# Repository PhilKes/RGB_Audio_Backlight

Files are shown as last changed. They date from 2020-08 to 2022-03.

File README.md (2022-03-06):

# RGB Audio Backlight
* WS2812B RGB LED Stripe + Arduino Nano
* Switching modes via Button
* Tweaking mode settings via Potentiometer

## See Instructables for details:  [Instructable](https://www.instructables.com/id/RGB-Backlight-MSGEQ7-Audio-Visualizer/)



## Audio Visualizer with MSGEQ7 Hardware
[RGBStripe_MSGEQ7](/RGBStripe_FFT)

* MSGEQ7 Circuit connected to Arduino
* Audio Spectrum Analyzer using MSGEQ7 Band outputs

## Audio Visualizer with Fast Fourier Transformation (FFT)

* Audio Spectrum Analyzer only using Software ([fix_fft](https://www.arduinolibraries.info/libraries/fix_fft))

### Schematic
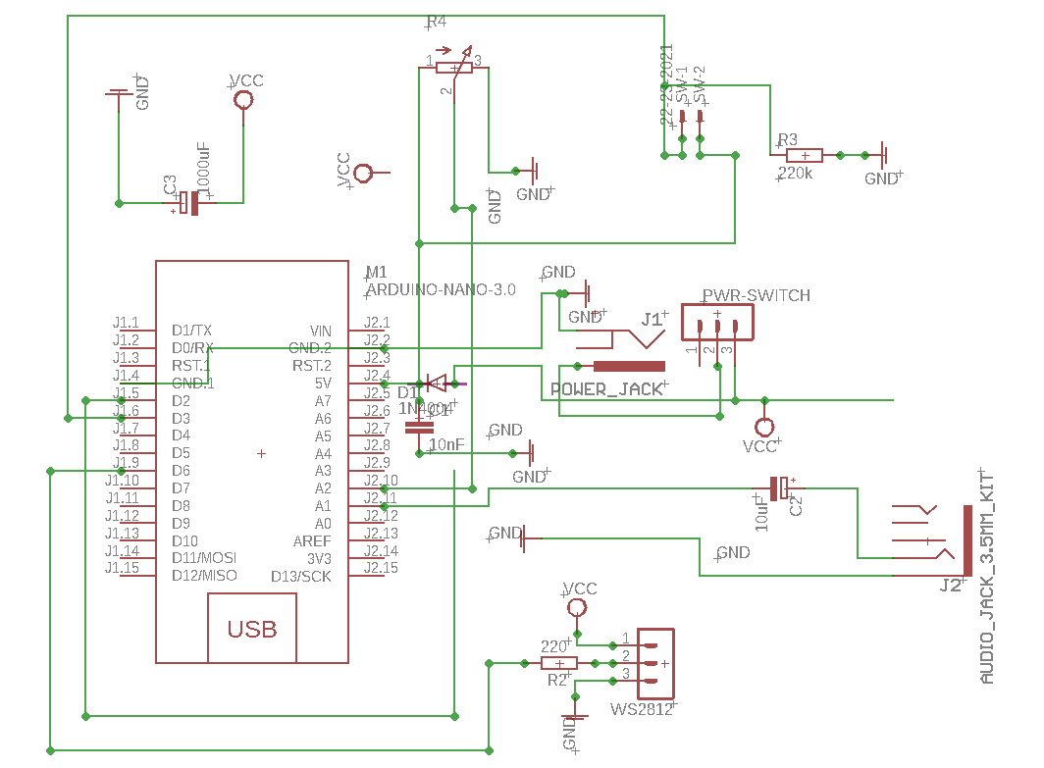
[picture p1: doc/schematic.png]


### 3D Printed Case
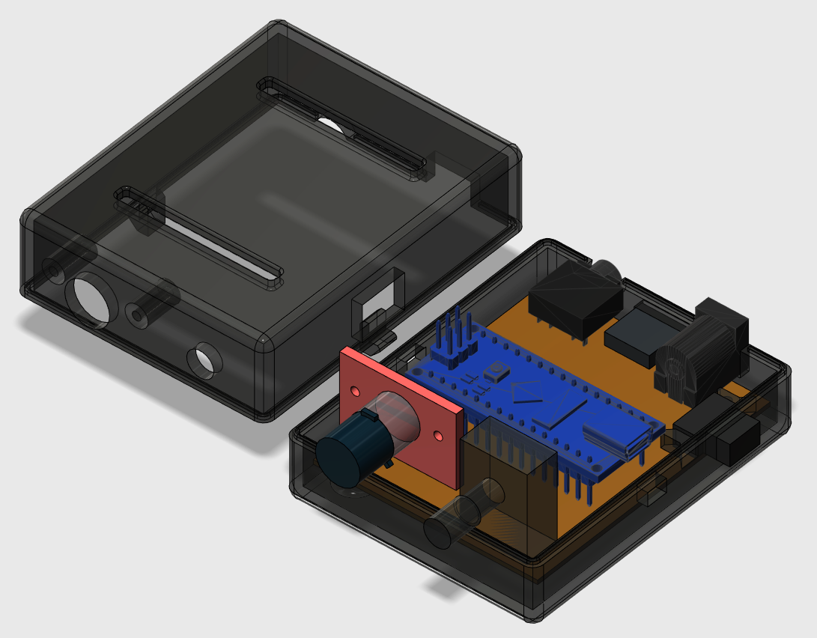
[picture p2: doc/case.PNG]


[RGBStripe_FFT](/RGBStripe_FFT)

* 3.5mm Aux connected to Analog Input of Arduino
* Audio Spectrum Analyzer using in Software FFT Algorithm to divide Signal in Audio Bands

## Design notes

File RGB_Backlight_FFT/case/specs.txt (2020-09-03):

Case:
Länge:69,90mm
Breite: 56.02mm
Wand Dicke: 2,4mm

button platine:
länge: 26mm
breite: 17mm

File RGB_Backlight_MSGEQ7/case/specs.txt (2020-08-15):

Touch Sensor:
länge 14mm
breite 11mm
dicke 1mm

Button Kappe
Höhe 9mm
durchmesser 10mm
ecken breit 1mm
ecken lang 3mm
pad höhe 7mm
pad durchmesser 10mm
pad -ecken übergang 1mm

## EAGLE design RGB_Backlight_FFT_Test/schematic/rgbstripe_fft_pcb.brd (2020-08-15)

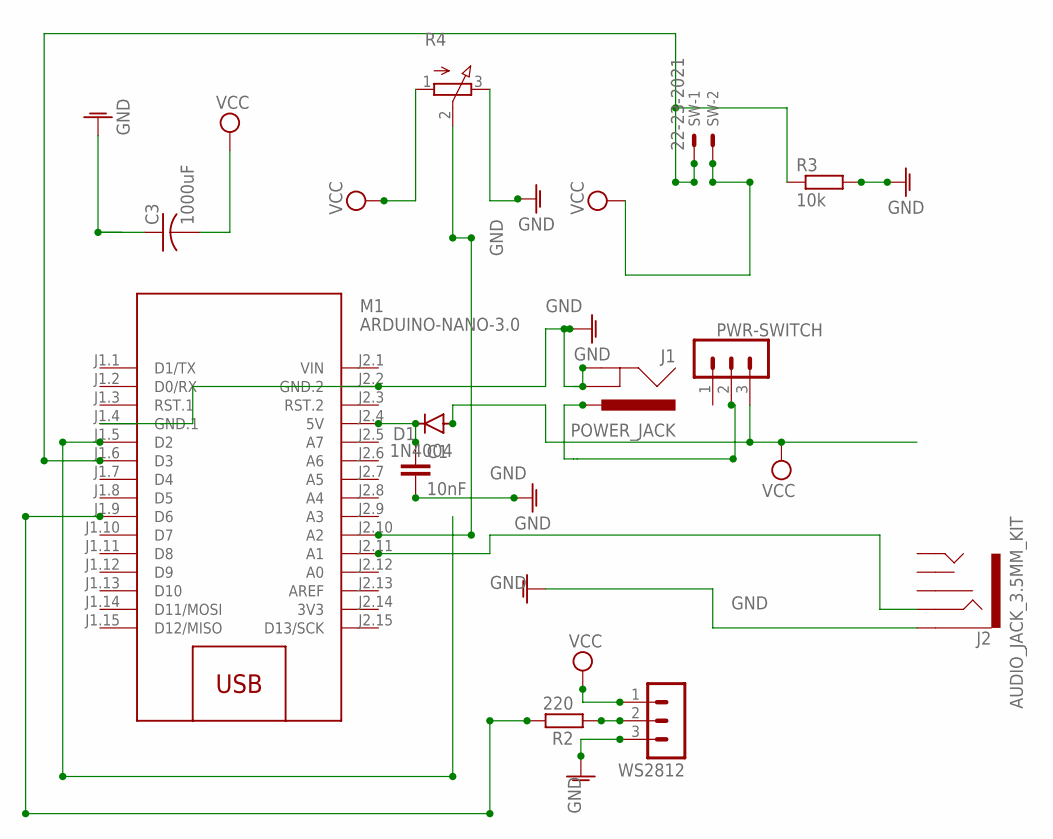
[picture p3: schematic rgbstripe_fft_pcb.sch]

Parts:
C1: 10nF; C025-025X050
C3: 1000uF; C050-024X044
D1: 1N4004; DO41-10
J1: POWER_JACK; POWER_JACK_PTH
J2: AUDIO_JACK_3.5MM_KIT; AUDIO-JACK-KIT
M1: ARDUINO-NANO-3.0
PWR-SWITCH: MA03-1
R2: 220; 0204/5
R3: 10k; 0204/5
R4: 3RP/1610N
SW: 22-23-2021
WS2812: MA03-1

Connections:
3V3: M1.J2.14 (3V3)
GND: C1.2, C3.1, J1.GND, J1.GNDBREAK, J2.SLEEVE, M1.J1.4 (GND.1), M1.J2.2 (GND.2), R3.2, R4.3 (E), WS2812.3
unnamed: C1.1, D1.C, M1.J2.4 (5V)
unnamed: J2.RING, M1.J2.11 (A1)
unnamed: M1.J1.9 (D6), R2.2
unnamed: M1.J2.10 (A2), R4.2 (S)
unnamed: R2.1, WS2812.2
unnamed: M1.J1.6 (D3), R3.1, SW.1
unnamed: J1.PWR, PWR-SWITCH.2
VCC: C3.2, D1.A, PWR-SWITCH.3, R4.1 (A), SW.2, WS2812.1
VIN: M1.J2.1 (VIN)

Board: 2 copper layers, 12 parts (0 on the bottom side), 9 nets, no tracks yet.

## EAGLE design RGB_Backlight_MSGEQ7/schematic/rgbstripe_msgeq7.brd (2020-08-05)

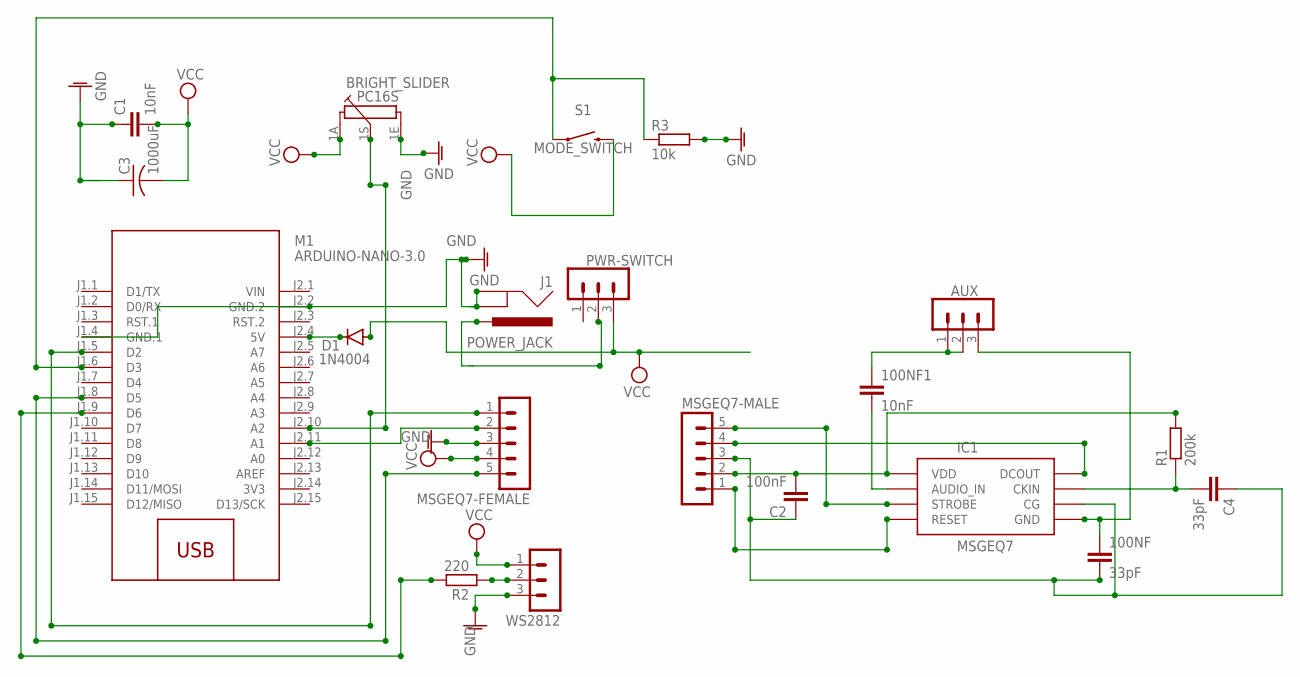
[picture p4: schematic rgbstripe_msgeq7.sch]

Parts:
100NF: 33pF; C025-025X050
100NF1: 10nF; C025-025X050
AUX: MA03-1
BRIGHT_SLIDER: PC16S
C1: 10nF; C025-025X050
C2: 100nF; C025-025X050
C3: 1000uF; C050-024X044
C4: 33pF; C025-025X050
D1: 1N4004; DO41-10
IC1: MSGEQ7P; DIP08
J1: POWER_JACK; POWER_JACK_PTH
M1: ARDUINO-NANO-3.0
MSGEQ7-FEMALE, MSGEQ7-MALE: MA05-1
PWR-SWITCH: MA03-1
R1: 200k; 0204/5
R2: 220; 0204/5
R3: 10k; 0204/5
S1: MODE_SWITCH; TACTILE_SWITCH_PTH_12MM
WS2812: MA03-1

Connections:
3V3: M1.J2.14 (3V3)
GND: BRIGHT_SLIDER.1E, C1.1, C3.1, J1.GND, J1.GNDBREAK, M1.J1.4 (GND.1), M1.J2.2 (GND.2), MSGEQ7-FEMALE.3, R3.2, WS2812.3
unnamed: D1.C, M1.J2.4 (5V)
unnamed: M1.J1.8 (D5), MSGEQ7-FEMALE.5
unnamed: M1.J2.11 (A1), MSGEQ7-FEMALE.2
unnamed: M1.J1.5 (D2), MSGEQ7-FEMALE.1
unnamed: C2.2, IC1.1 (VDD), MSGEQ7-MALE.2, R1.2
unnamed: 100NF.2, C2.1, C4.1, IC1.6 (CG), MSGEQ7-MALE.3
unnamed: IC1.3 (DCOUT), MSGEQ7-MALE.4
unnamed: IC1.4 (STROBE), MSGEQ7-MALE.5
unnamed: IC1.7 (RESET), MSGEQ7-MALE.1
unnamed: 100NF1.1, AUX.1, AUX.2
unnamed: C4.2, IC1.8 (CKIN), R1.1
unnamed: 100NF.1, AUX.3, IC1.2 (GND)
unnamed: 100NF1.2, IC1.5 (AUDIO_IN)
unnamed: M1.J1.9 (D6), R2.2
unnamed: BRIGHT_SLIDER.1S, M1.J2.10 (A2)
unnamed: R2.1, WS2812.2
unnamed: M1.J1.6 (D3), R3.1, S1.1
unnamed: J1.PWR, PWR-SWITCH.2
VCC: BRIGHT_SLIDER.1A, C1.2, C3.2, D1.A, MSGEQ7-FEMALE.4, PWR-SWITCH.3, S1.3 (2), WS2812.1
VIN: M1.J2.1 (VIN)

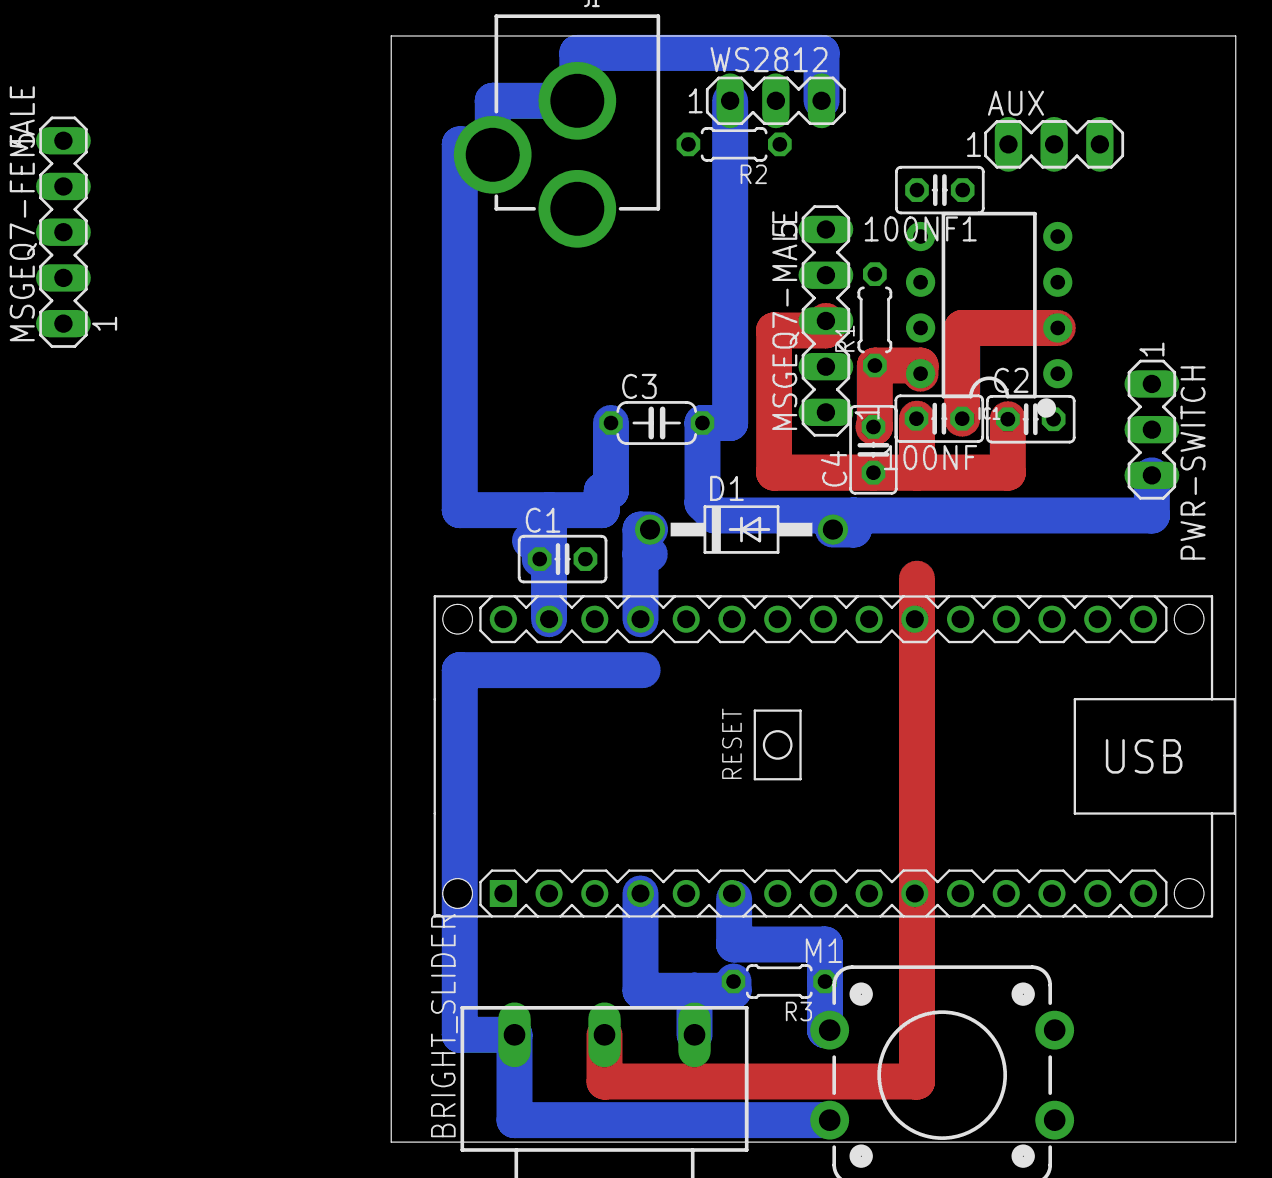
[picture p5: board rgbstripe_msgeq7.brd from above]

Board: 2 copper layers, 46.9 x 61.5 mm, 20 parts (0 on the bottom side), 20 nets.

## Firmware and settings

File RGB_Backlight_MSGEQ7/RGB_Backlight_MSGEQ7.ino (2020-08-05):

#include <Adafruit_NeoPixel.h>
#ifdef __AVR__
#include <avr/power.h>
#endif

#define LED_DATA 6
#define POT_BRIGHTNESS A2

#define NUM_LEDS 45         // <-- CHANGE TO NUMBER OF LEDS ON YOUR STRIP
#define BTN_PIN 3           // Button on Interrupt Pin 3         
#define BRIGHTNESS 255
#define MAX_MODE 7          // Amount of modes (used in Switch-Case)
#define DELAY 13

//  MSGEQ7 Pin Connections
#define MSGEQ_OUT A1
#define STROBE 2
#define RESET 5

//MINIMUM DELAY FOR BUTTON TO TRIGGER NEXT ISR
#define ISR_DELAY 400
Adafruit_NeoPixel strip = Adafruit_NeoPixel(NUM_LEDS, LED_DATA, NEO_GRB + NEO_KHZ800);

byte neopix_gamma[] = {
  0,  0,  0,  0,  0,  0,  0,  0,  0,  0,  0,  0,  0,  0,  0,  0,
  0,  0,  0,  0,  0,  0,  0,  0,  0,  0,  0,  0,  1,  1,  1,  1,
  1,  1,  1,  1,  1,  1,  1,  1,  1,  2,  2,  2,  2,  2,  2,  2,
  2,  3,  3,  3,  3,  3,  3,  3,  4,  4,  4,  4,  4,  5,  5,  5,
  5,  6,  6,  6,  6,  7,  7,  7,  7,  8,  8,  8,  9,  9,  9, 10,
  10, 10, 11, 11, 11, 12, 12, 13, 13, 13, 14, 14, 15, 15, 16, 16,
  17, 17, 18, 18, 19, 19, 20, 20, 21, 21, 22, 22, 23, 24, 24, 25,
  25, 26, 27, 27, 28, 29, 29, 30, 31, 32, 32, 33, 34, 35, 35, 36,
  37, 38, 39, 39, 40, 41, 42, 43, 44, 45, 46, 47, 48, 49, 50, 50,
  51, 52, 54, 55, 56, 57, 58, 59, 60, 61, 62, 63, 64, 66, 67, 68,
  69, 70, 72, 73, 74, 75, 77, 78, 79, 81, 82, 83, 85, 86, 87, 89,
  90, 92, 93, 95, 96, 98, 99, 101, 102, 104, 105, 107, 109, 110, 112, 114,
  115, 117, 119, 120, 122, 124, 126, 127, 129, 131, 133, 135, 137, 138, 140, 142,
  144, 146, 148, 150, 152, 154, 156, 158, 160, 162, 164, 167, 169, 171, 173, 175,
  177, 180, 182, 184, 186, 189, 191, 193, 196, 198, 200, 203, 205, 208, 210, 213,
  215, 218, 220, 223, 225, 228, 231, 233, 236, 239, 241, 244, 247, 249, 252, 255
};

uint16_t time_since_isr=0;
boolean breakMode=false;
uint8_t mode=0;
//  Buffer arrays for Audio Analyzer Mode
int spectrumValue[8];
uint8_t mapValue[8];
uint32_t audioBuffer[NUM_LEDS];
int filter = 0;

uint16_t brightness;

bool countUp=true;
uint32_t lastColor=0;

void setup() {
  // This is for Trinket 5V 16MHz, you can remove these three lines if you are not using a Trinket
#if defined (__AVR_ATtiny85__)
  if (F_CPU == 16000000) clock_prescale_set(clock_div_1);
#endif
  // Init Strip with max. Brightness
  brightness = BRIGHTNESS;
  strip.setBrightness(BRIGHTNESS);
  strip.begin();
  strip.show();

  //Serial connection for debug info
  Serial.begin(9600);
  Serial.println("START");
  pinMode(MSGEQ_OUT, INPUT);
  pinMode(STROBE, OUTPUT);
  pinMode(RESET, OUTPUT);
  pinMode(BTN_PIN, INPUT);
  
  digitalWrite(RESET, LOW);
  digitalWrite(STROBE, HIGH);

  pinMode(POT_BRIGHTNESS, INPUT);
  // Attach interrupt to Pin 3 for Push Button to switch modes
  attachInterrupt(1, changeMode, RISING);
}

void loop() {
  breakMode=false;
  switch(mode){
    case 0:
      Serial.println("White");
      plainColorNoBright(255,255,255);
      break;
   case 1:                        // CHANGE IF NOT USING MSGEQ7
      Serial.println("Music");
      musicAnalyzer();
      break;
   case 2:
      Serial.println("Red");
      plainColor(255,0,0);
      break;
    case 3:
      Serial.println("Green");
      plainColor(0,255,0);
      break;
    case 4:
      Serial.println("Blue");
      plainColor(0,0,255);
      break;
   case 5:
      Serial.println("Raindow");
      rainbowFade2White(400,255,10);
      break;
   case 6:
      Serial.println("ColorRoom");
      colorRoom();
      break;
   default:
      Serial.println("DEFAULT");
      pulseWhite(300);
      break;
  }
}

/* ISR for Button to switch modes */
void changeMode() {
  if(millis()-time_since_isr>ISR_DELAY){
    Serial.println("PRESSED");
    time_since_isr=millis();
    mode=(mode+1)%MAX_MODE;
    breakMode=true;
  }
}
/* Checks if Potentiometer value has changed, sets new Brightness and return true */
boolean checkBrightness(){
  //WS2812 takes value between 0-255
  uint16_t bright = map(constrain(analogRead(POT_BRIGHTNESS),0,1024), 0, 1024, 10, 255);
  if (abs(bright-brightness)>10){
    brightness = bright;
    strip.setBrightness(brightness);
    return true;
  }
  return false;
}

//Animation showing fading rainBow color along the strip
void rainbowFade2White(uint8_t wait, int rainbowLoops, int whiteLoops) {
  float fadeMax = 100.0;
  int fadeVal = fadeMax;
  uint32_t wheelVal;
  int redVal, greenVal, blueVal;

  for (int k = 0 ; k < rainbowLoops ; k ++) {
    for (int j = 0; j < 256; j++) { 
      for (int i = 0; i < strip.numPixels(); i++) {
        wheelVal = Wheel(((i * 256 / strip.numPixels()) + j) & 255);
        redVal = red(wheelVal) * float(fadeVal / fadeMax);
        greenVal = green(wheelVal) * float(fadeVal / fadeMax);
        blueVal = blue(wheelVal) * float(fadeVal / fadeMax);
        strip.setPixelColor( i, strip.Color( redVal, greenVal, blueVal ) );
      }
      if(breakMode)
        return;
        checkBrightness();
        strip.show();
        delay(wait);
    }
  }
  delay(500);
}

// Use Brightness Potentiometer to change Color
void colorRoom(){
    strip.setBrightness(255);
    uint32_t colorNew = map(constrain(analogRead(POT_BRIGHTNESS),0,1024), 0, 1024, 0, 255);
    if (abs(colorNew-lastColor)>10){
      lastColor=colorNew;
      for (int i = 0; i < strip.numPixels(); i++)
             strip.setPixelColor(i, Wheel((colorNew) & 255)); 
      strip.show();
    }
    delay(10);
}

void plainWhite(){
  for (int i = 0; i < strip.numPixels(); i++) {
        strip.setPixelColor( i, strip.Color( 255, 255, 255 ) );
   }
  strip.show();
  while(!breakMode){
    if(checkBrightness())
      strip.show();
  }
}

//Shows plain color along the strip
void plainColor(uint8_t red,uint8_t green,uint8_t blue){
  for (int i = 0; i < strip.numPixels(); i++)
        strip.setPixelColor( i, strip.Color( red, green, blue ) );
  strip.show();
  while(!breakMode){
    if(checkBrightness())
      strip.show();
  }
}

//Shows plain color along the strip
void plainColorNoBright(uint8_t red,uint8_t green,uint8_t blue){
  for (int i = 0; i < strip.numPixels(); i++)
        strip.setPixelColor( i, strip.Color( red, green, blue ) );
  strip.show();
  while(!breakMode){
    delay(100);
  }
}
void musicAnalyzer(){
  while(true){
    checkBrightness();
    if(breakMode)
      return;
    //Reset MSGEQ
    digitalWrite(RESET, HIGH);
    digitalWrite(RESET, LOW);
    //Read all 8 Audio Bands
    for (int i = 0; i < 8; i++){
      digitalWrite(STROBE, LOW);
      delayMicroseconds(30);
      spectrumValue[i] = analogRead(MSGEQ_OUT);
      spectrumValue[i] = constrain(spectrumValue[i], filter, 1023);
      digitalWrite(STROBE, HIGH);
      //Skip band 3 (seems to be random for my MSGEQ7, but feel free to check yours
      if (i == 3)
        continue;
      mapValue[i] = map(spectrumValue[i], filter, 1023, 0, 255);
      if (mapValue[i] < 50)
        mapValue[i] = 0;
    }
    //Shift LED values forward
    for (int k = NUM_LEDS - 1; k > 0; k--) {
      audioBuffer[k] = audioBuffer[k - 1];
    }
    //Uncomment / Comment above to Shift LED values backwards
    //for (int k = 0; k < NUM_LEDS-1; k++) {
    //  audioBuffer[k] = audioBuffer[k + 1];
    //}
    
    //Load new Audio value to first LED
    //Uses band 0,2,4 (Bass(red), Middle(green), High(blue) Frequency Band)
    //Lowest 8Bit: Blue , Middle Green , Highest Red
    //Use audioBuffer[NUM_LEDS-1] when using LED shift backwards!
    audioBuffer[0] = mapValue[5]; //RED
    audioBuffer[0] = audioBuffer[0] << 16;
    audioBuffer[0] |= ((mapValue[2] /2) << 8);  //GREEN
    audioBuffer[0] |= (mapValue[4]/4);         //BLUE
    
    //Send new LED values to WS2812
    for ( int i = 0; i < NUM_LEDS; i++)
      strip.setPixelColor(i, strip.Color(audioBuffer[i] >> 16, (audioBuffer[i] >> 8)&B11111111, audioBuffer[i]&B11111111));
    strip.show();
    delay(DELAY);
  }
}

//  FROM EXAMPLES
// Fill the dots one after the other with a color
void colorWipe(uint32_t c, uint8_t wait) {
  for (uint16_t i = 0; i < strip.numPixels(); i++) {
    strip.setPixelColor(i, c);
    strip.show();
    delay(wait);
  }
}

void pulseWhite(uint8_t wait) {
  for (int j = 0; j < 256 ; j++) {
    for (uint16_t i = 0; i < strip.numPixels(); i++) {
      strip.setPixelColor(i, strip.Color(0, 0, 0, neopix_gamma[j] ) );
    }
    checkBrightness();
    if(breakMode)
      return;
    delay(wait);
    strip.show();
  }
  for (int j = 255; j >= 0 ; j--) {
    for (uint16_t i = 0; i < strip.numPixels(); i++) {
      strip.setPixelColor(i, strip.Color(0, 0, 0, neopix_gamma[j] ) );
    }
    delay(wait);
    strip.show();
  }
}




void whiteOverRainbow(uint8_t wait, uint8_t whiteSpeed, uint8_t whiteLength ) {

  if (whiteLength >= strip.numPixels()) whiteLength = strip.numPixels() - 1;

  int head = whiteLength - 1;
  int tail = 0;

  int loops = 3;
  int loopNum = 0;

  static unsigned long lastTime = 0;


  while (true) {
    for (int j = 0; j < 256; j++) {
      for (uint16_t i = 0; i < strip.numPixels(); i++) {
        if ((i >= tail && i <= head) || (tail > head && i >= tail) || (tail > head && i <= head) ) {
          strip.setPixelColor(i, strip.Color(0, 0, 0, 255 ) );
        }
        else {
          strip.setPixelColor(i, Wheel(((i * 256 / strip.numPixels()) + j) & 255));
        }

      }

      if (millis() - lastTime > whiteSpeed) {
        head++;
        tail++;
        if (head == strip.numPixels()) {
          loopNum++;
        }
        lastTime = millis();
      }

      if (loopNum == loops) return;

      head %= strip.numPixels();
      tail %= strip.numPixels();
      strip.show();
      delay(wait);
    }
  }

}
void fullWhite() {

  for (uint16_t i = 0; i < strip.numPixels(); i++) {
    strip.setPixelColor(i, strip.Color(0, 0, 0, 255 ) );
  }
  strip.show();
}


// Slightly different, this makes the rainbow equally distributed throughout
void rainbowCycle(uint8_t wait) {
  uint16_t i, j;

  for (j = 0; j < 256 * 5; j++) { // 5 cycles of all colors on wheel
    for (i = 0; i < strip.numPixels(); i++) {
      strip.setPixelColor(i, Wheel(((i * 256 / strip.numPixels()) + j) & 255));
    }
    strip.show();
    delay(wait);
  }
}

void rainbow(uint8_t wait) {
  uint16_t i, j;

  for (j = 0; j < 256; j++) {
    for (i = 0; i < strip.numPixels(); i++) {
      strip.setPixelColor(i, Wheel((i + j) & 255));
    }
    strip.show();
    delay(wait);
  }
}

// Input a value 0 to 255 to get a color value.
// The colours are a transition r - g - b - back to r.
uint32_t Wheel(byte WheelPos) {
  WheelPos = 255 - WheelPos;
  if (WheelPos < 85) {
    return strip.Color(255 - WheelPos * 3, 0, WheelPos * 3, 0);
  }
  if (WheelPos < 170) {
    WheelPos -= 85;
    return strip.Color(0, WheelPos * 3, 255 - WheelPos * 3, 0);
  }
  WheelPos -= 170;
  return strip.Color(WheelPos * 3, 255 - WheelPos * 3, 0, 0);
}

uint8_t red(uint32_t c) {
  return (c >> 16);
}
uint8_t green(uint32_t c) {
  return (c >> 8);
}
uint8_t blue(uint32_t c) {
  return (c);
}

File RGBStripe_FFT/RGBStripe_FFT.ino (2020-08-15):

#include "fix_fft.h"                                  //library to perfom the Fast Fourier Transform

#include <SPI.h>                                      //SPI library
#include <Wire.h>                                     //I2C library for OLED
#include <Adafruit_GFX.h>                             //graphics library for OLED
#include <Adafruit_SSD1306.h>                         //OLED driver

#define OLED_RESET 4                                  //OLED reset, not hooked up but required by library
Adafruit_SSD1306 display(OLED_RESET);                 //declare instance of OLED library called display

char im[128], data[128];                              //variables for the FFT
char x = 0, ylim = 30;                                //variables for drawing the graphics
int i = 0, val;                                       //counters

#define DEBUG 0

void setup() {
  #if DEBUG
  Serial.begin(115200);
  #endif
  display.begin(SSD1306_SWITCHCAPVCC, 0x3C);          //begin OLED @ hex addy 0x3C
  display.setTextSize(1);                             //set OLED text size to 1 (1-6)
  display.setTextColor(WHITE);                        //set text color to white
  display.clearDisplay();                             //clear display
  analogReference(DEFAULT);                           // Use default (5v) aref voltage.
}

void loop() {

  int min=1024, max=0;                                //set minumum & maximum ADC values
  for (i = 0; i < 128; i++) {                         //take 128 samples
    val = analogRead(A0);                             //get audio from Analog 0
    data[i] = val ;                          //each element of array is val/4-128
    im[i] = 0;                                        //
    if(val>max) max=val;                              //capture maximum level
    if(val<min) min=val;                              //capture minimum level
  };
    
  fix_fft(data, im, 7, 0);                            //perform the FFT on data
  
  display.clearDisplay();                             //clear display
  for (i = 1; i < 64; i++) {                          // In the current design, 60Hz and noise
    int dat = sqrt(data[i] * data[i] + im[i] * im[i]);//filter out noise and hum
    display.drawLine(i*2 + x, ylim, i*2 + x, ylim - dat, WHITE); // draw bar graphics for freqs above 500Hz to buffer
    #if DEBUG
    Serial.print(dat);
    Serial.print(" ");
    #endif
  };      
  #if DEBUG            
  Serial.println();
  #endif
  display.display();                                  //show the buffer

}

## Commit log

2019-02-26 fixed Interrupt
2020-08-05 schematic added
    [rgb_stripe_control.brd, rgb_stripe_control.sch]
2020-08-15 added Sketch + Schematic using FFT instead of MSGEQ7 Circuit
    [rgb_controller.fzz, rgb_stripe_control.brd, rgb_stripe_control.sch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]
2020-08-15 RGBStripe_MSGEQ7 added
    [rgb_controller.fzz, rgbstripe_msgeq7.brd, rgbstripe_msgeq7.sch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]
2020-08-15 renamed Sketches
    [rgb_controller.fzz, rgbstripe_fft_lochraster.brd, rgbstripe_fft_lochraster.sch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]
2020-08-20 case: 123Design case added + Sketches Updates
    [finished.stl, rgbstripe_fft_lochraster.brd, rgbstripe_fft_lochraster.sch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]
2020-09-02 finished 3D print case
    [finished.stl, rgbstripe_fft_lochraster.brd]
2020-09-03 Case fixes
2021-08-08 fix model .STL files
    [RGB_Backlight_FFT.ino]

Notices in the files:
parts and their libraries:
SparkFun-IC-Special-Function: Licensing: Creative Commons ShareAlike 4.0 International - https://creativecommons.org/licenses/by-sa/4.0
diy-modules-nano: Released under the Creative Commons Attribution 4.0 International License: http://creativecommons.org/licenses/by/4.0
